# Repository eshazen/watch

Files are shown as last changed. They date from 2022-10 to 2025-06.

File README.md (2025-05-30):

# Smart Watch

See also:  [SOFTWARE.md](SOFTWARE.md)
<br> [BUILD.md](BUILD.md)

Imagining a device similar to a smart watch, but not intended to
connect to a phone and generate alerts.  Instead, I'd like:

* Large, easy-to-read e-ink time display
* Auxiliary info (possibly selected using button):
   * Multiple timezones
   * Alarm/timer time
   * Weather info
   * Any other not-quite realtime info pushed via WiFi

The watch would link to base stations at home and at work for updates.
This could be WiFi (power hungry!), or something like RFM69 (915 MHz).

The idea would be that the watch has WiFi but only powers up every 10min or
so and tries to connect to the last AP, otherwise tries a short list of AP.
Some fairly smart algorithm should recognize when not near an AP and give up,
checking at longer intervals.  A button press should be available to force
WiFi update.

## Rev 1.0

Ordered PCBs and BOM parts (Mouser) on 12/2/22.  

* [schematic](watch-pcb/watch-sch.pdf)

Radio is RFM69HCW (915MHz).  Display is waveshire e-link 1.54 in
(200x200 resolution).  RTC is PCF85263A.
There's an 8-pin (2x4) 2mm "service" connector with pinout:

| Pin | Function |
|-----|---|
| 1 | 3.3V |
| 2 | MOSI |
| 3 | MISO |
| 4 | SCK |
| 5 | nRESET |
| 6 | UART TX  |
| 7 | UART RX  |
| 8 | GND |

ATMega328 pin assignments:

| Pin | Function | Notes |
|-----|---|---|
| PB0 | eRST | e-ink reset |
| PB1 | eDC | e-ink data/control  |
| PB2 | RF_CS | Radio chip select |
| PB3 | MOSI | for radio and e-ink |
| PB4 | MISO | radio MISO |
| PB5 | SCK | for radio and e-ink |
| PB6 | LED1 | |
| PB7 | LED2 | |
|-----|----------|---------------------|
| PC0 | RF_RST | Radio reset |
| PC1 | SW1 | (not installed) |
| PC2 | SW2 | |
| PC3 | RTC_INT  | RTC interrupt |
| PC4 | RTC_SCL  | RTC I2C clock |
| PC5 | RTC_SDA  | RTC I2C data |
| PC6 | nRESET | MCU reset |
|-----|----------|---------------------|
| PD0 | RxD | UART input data |
| PD1 | TxD | UART output data |
| PD2 | SW3 | |
| PD3 | SW4 | |
| PD5 | DIO0 | Radio DIO0 |
| PD6 | eCS | e-ink chip select |
| PD7 | eBUSY | e-ink busy |

3D PCB view: 

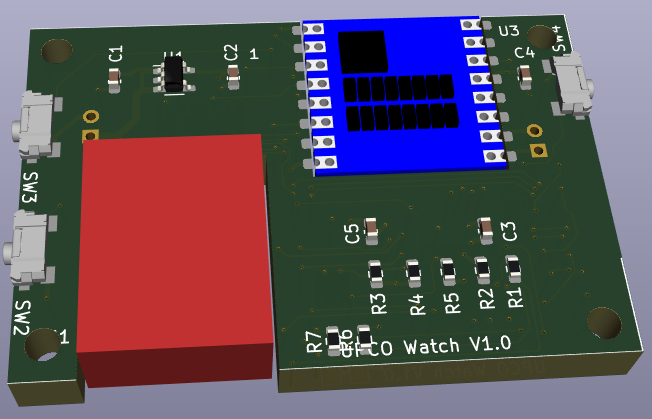
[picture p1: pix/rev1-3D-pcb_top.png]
front
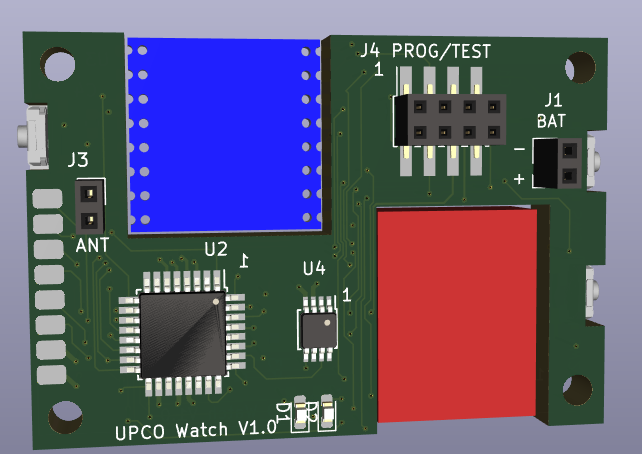
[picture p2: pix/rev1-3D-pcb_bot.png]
back
 

### Display

Ordered a black/red display from buydisplay.com.  This works ok but has
a ~15s refresh time and doesn't support fast/partial refresh.  My bad!

Ordered another from waveshare which is monochrome and does support
partial refresh.  Holding off on buying anything else until the display
part is working reasonably.

* Waveshare [page](https://www.waveshare.com/product/displays/e-paper/1.54inch-e-paper-module.htm?___SID=U)
[wiki](https://www.waveshare.com/wiki/1.54inch_e-Paper_Module) [data](https://www.waveshare.com/w/upload/e/e5/1.54inch_e-paper_V2_Datasheet.pdf)

This is reasonable, just a bit big.  Another alternative is the waveshare
1.02inch display.

### Radio

Meanwhile, Carlos (of MLRC) suggests BLE or VHF radio as an alternative
to WiFi.  This would require a bit of setup but would be much lower power.

#### VHF/UHF

RFM69 [data](https://cdn.sparkfun.com/datasheets/Wireless/General/RFM69HCW-V1.1.pdf) is 
interesting, but needs a 3 inch antenna.  Possibly it would work
OK if wrapped around the watch band?  These things are cheap ($6.50 for COM-13909 from
Sparkfun).  3.3V.  Needs 16mA to receive, 16..130mA to transmit (depends on settings).
Bit rates are modem-ish up to 156k.  Claims 50m range indoors.
Module is about 0.8" x 0.8" (20.3mm)

nRF24L01 and friends.  2.4GHz.  Bit rate s 250/1M/2M.  Power for Rx:
8.9-13.5mA Power for Tx: 8-11mA.  Fancier protocol with packet
retransmit, etc.  $21 each for WRL-00691.

#### ESP-01

ESP-01 Power Consumption:  
* 170mA working worst case
* 0.9mA "light sleep"
* 10uA "deep sleep"

Datasheet says "...sleep 300s and waking up to connect to the AP
(taking about 0.3~1s), the overall average current is less than 1mA.
Not clear how this is affected if multiple AP must be tried.  Need
to get some ESP-01 and play with them.

So we're looking at ~1mA minimum average power with capability to
deliver ~200mA.  For few days running it would be nice to have
~100mAh.

It seems that on ESP-01 modules you need to wire pin 8 to nRESET so it
can self-wake out of deep sleep.  Otherwise you can just call
ESP.deepSleep(0) and then use the MCU to pulse reset to wake it up.
(see
[note](https://www.tech-spy.co.uk/2019/04/enable-deep-sleep-esp-01/))

## Doco

* Display: [Mfgr page](https://www.buydisplay.com/red-1-54-inch-e-ink-display-module-200x200-for-arduino-raspberry-pi)
* [eInk.md](eInk.md)

## Parts?

* MCU:  ATMega1281-16AUR (64-TQFP)
   * Chosen for it's 8K RAM size so it can hold a 200x200 bitmap for the display
* RTC: 
   * Nisshinbo R2043T-E2-F (2129-R2043T-E2-FCT-ND).  10-VFSOP
   * Nisshinbo R2025S-E2-FE (2129-R2025S-E2-FECT-ND).  14-SOIC
* Thru pin socket
   * Mill-Max 0305-2-15-80-47-27-10-0  (0305-2-15-80-47-27-10-0)
* Side-mount switch
   * Panasonic EVQ-P4MB3K (P15507CT-ND)
* Battery Holder for CR1216
   * Linx BAT-HLD-012-SMT (BAT-HLD-012-SMT-ND)
* or Lipo battery.  There seem to be 100mAh batts 18x14.7mm which are
  cheap ($16/4 on Amazon with a little USB charger thing).  These are
  3.7V so we need a small-ish 3.3V LDO.
* WiFi
   * ESP-01 [data](https://www.microchip.ua/wireless/esp01.pdf)

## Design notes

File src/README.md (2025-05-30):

# Software for the watch

`watch` - simulation to run on xforms toolkit

`blinky` - initial LED/button test for AVR

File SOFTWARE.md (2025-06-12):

# Watch software

Initial software outline:

* Initialize RTC for 1 minute periodic interrupt
* Initialize AVR to go to sleep and wake on pin change interrupt from RTC
* On wakeup:  display time

Also need to provide some interface to set the time

## RTC

Basically working.  Time registers can be R/W and update as expected.

### Initialization

Set `TSPM[1:0] = 1` (nINTB output)

Set `INTA_enable` (addr 0x29) to `b'01000000'` (enable only periodic interrupt)

Set `Function` (addr 0x28) to `b'01000111'` (1 min periodic) -or-
<br> `b'00100111'` (1 sec periodic)

### Set / Read time

Time is in addresses 1-3 as BCD

### Interrupts

Setup AVR to interrupt on pin change on PC3.
Sleep to power-down mode and wake on interrupt.

Some example code:

```
set_sleep_mode(SLEEP_MODE_PWR_DOWN);
sleep_enable();
sleep_mode();
// wait for wake-up
sleep_disable();
power_all_enable();
```

## UART

UART working at 1200 baud (not 9600) with default 1MHz clock.

Need to find / recreate my_gets using the stdio hack.

## Display

Working after porting the code from Arduino.
The main limitation is the 1k maximum bitmap (64 x 128).

It would be nice to display an analog clock face.
This is complicated by the fact that the E-Ink display
is 200x200 and we don't have enough RAM (200x200/8=5000 bytes)
for a bitmap.

One solution is a partial bitmap (e.g. 64x128 = 1k), and
a bit of code which takes a display list and iterates
over it 8 times, clipping the lines into regions,
sending each to the display as it completes.

    /---- 200 ------\
    +----+----+----+----+ \
    | 64 | 64 | 64 | 64 | |
	|    |    |    |    | |
	|    |    |    |    | |
	|    |    |    |    | 200 
    +----+----+----+----+ |
	|    |    |    |    | |
	|    |    |    |    | |
	|    |    |    |    | /
	|    |    |    |    |
    +----+----+----+----+

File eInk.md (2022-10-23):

# EP-EPM0154-2R Software

## Installation

This display family is provided with some more-or-less working examples.  Installation steps:

Grab the zip from either the manufacturer page or local copy in `arduino` folder as 
`ER-EPM0154-2_Arduino_Tutorial.zip`.
This contains 3 sets of `Examples...` and `Libraries...` directories.

Copy the appropriate (in our case, the '..-2R') `Libraries` folder to the Arduino libraries
location, normally `~/Arduino/libraries/ER-EPM0154-2R`.

Then, make the following edits:

In `epdif.cpp` change "`#include <spi.h>`" to "`#include <SPI.h>`"

In `epdif.h` change "`#include <arduino.h>`" to "`#include <Arduino.h>`"

Now the example runs, at least in Arduino 1.8.19 under Ubuntu 22.04.

## Class Library

Here are the prototypes for `ER-EPM0154-2R.cpp`:

    Epd();
    ~Epd();
    int  Init(void);
    void SendCommand(unsigned char command);
    void SendData(unsigned char data);
    void WaitUntilIdle(void);
    void Reset(void);
     void SetFrameMemoryBlack(
        const unsigned char* image_buffer,
        int x,
        int y,
        int image_width,
        int image_height
    ); 
      void SetFrameMemoryRed(
        const unsigned char* image_buffer,
        int x,
        int y,
        int image_width,
        int image_height
    );   
    void SetFrameMemory(const unsigned char* frame_buffer_black, const unsigned char* frame_buffer_red);
    void ClearFrameMemory(void);
    void DisplayFrame(void);
    void Sleep(void);

### Use

Create one instance of `Epd` and use for all interactions with the display.

For drawing, the `paint` class manages a pixel buffer in RAM (keep in
mind RAM limitations!).  Each instance has a pointer to RAM area,
width, height and rotate flag (one of ROTATE_0, ROTATE_90, ROTATE_180,
ROTATE_270).  This is a 1-bit deep buffer, so you need two of them
for black and red.

There are a bunch of methods to draw pixels, characters, strings,
lines, rectangles, and circles to the buffer.

So, typically:

    unsigned char image[1200];
    Paint paint(image, 0, 0);
    Epd epd;

    if (epd.Init() != 0) fail();
    epd.ClearFrameMemory();
	
To write a string:

    paint.Clear(UNCOLORED);
    paint.DrawStringAt(0, 4, "Hello world!", &Font16, COLORED);
    epd.SetFrameMemoryBlack(paint.GetImage(), 0, 10, paint.GetWidth(), paint.GetHeight());
    epd.DisplayFrame();

### Methods

#### `Epd::Epd()`

Sets member variables for pin names (reset, dc, cs, bus) and width,
height from constants. Pins are defined in `epdif.h` while `width` and
`height` are define in `ER-EPM0154-2R.h`.

#### `Epd::Init()`

Initialize SPI via `EpdIf::IfINit()` (in `epdif.cpp`).  Sets pin modes
and initialize SPI.

#### `void Epd::SetFrameMemoryRed(`
#### `void Epd::SetFrameMemoryBlack(`

    const unsigned char* image_buffer,
    int x,
    int y,
    int image_width,
    int image_height)`
	
Copy image buffer to frame memory at specified coordinates.  Don't update display	

#### `void Epd::SetFrameMemory(const unsigned char* frame_buffer_black, const unsigned char* frame_buffer_red)`

Set frame memory from images in flash.

#### `Paint::Paint(unsigned char* image, int width, int height)`

Create a paint instance with pointer to RAM.  Width and height may be
set later (could be 0,0)

#### `Paint::Clear(int colored)`

Clear the image (slowly, with loop, calling `DrawAbsolutePixel`)

#### `void Paint::DrawAbsolutePixel(int x, int y, int colored)`

Set a pixel in the buffer (ignores rotation)

#### `void Paint::DrawPixel(int x, int y, int colored)`

Set a pixel in the buffer, taking into account rotation

#### `void Paint::DrawCharAt(int x, int y, char ascii_char, sFONT* font, int colored)`

Draw a character.  Font choices supplied (constants, stored in flash,
128 chars per font):

    Font8  (5 x 8)    1 byte/char  752 bytes
	Font12 (7 x 12)   1 byte/char  1128 bytes
	Font16 (11 x 16)  2 byte/char  3008 bytes
	Font20 (14 x 20)  2 byte/char  3760 bytes
	Font24 (17 x 24)  3 byte/char  6768 bytes
	
#### `Paint::DrawStringAt(int x, int y, const char* text, sFONT* font, int colored)`

Draw a string from RAM.  Note that there is (currently) no function to
write strings stored in flash.

There are various drawing functions:

#### `void Paint::DrawLine(int x0, int y0, int x1, int y1, int colored)`
#### `void Paint::DrawHorizontalLine(int x, int y, int line_width, int colored)`
#### `void Paint::DrawVerticalLine(int x, int y, int line_height, int colored)`
#### `void Paint::DrawRectangle(int x0, int y0, int x1, int y1, int colored)`
#### `void Paint::DrawFilledRectangle(int x0, int y0, int x1, int y1, int colored)`
#### `void Paint::DrawCircle(int x, int y, int radius, int colored)`
#### `void Paint::DrawFilledCircle(int x, int y, int radius, int colored)`

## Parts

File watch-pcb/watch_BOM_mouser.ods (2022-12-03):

Item | Qty | Reference(s) | Value | LibPart | Footprint | CatNo
1 | 2 | C1, C2 | 1uF | Device:C_Small | Capacitor_SMD:C_0603_1608Metric | 187-CL10B105KP8NNNC | Mouser
2 | 3 | C3, C4, C5 | 0.1uF | Device:C_Small | Capacitor_SMD:C_0603_1608Metric | 603-CC603KRX7R7BB104 | Mouser
3 | 2 | D1, D2 | LED | Device:LED | LED_SMD:LED_0603_1608Metric_Pad1.05x0.95mm_HandSolder | 755-SML-D12U8WT86 | Mouser
5 | 1 | J1 | Conn_01x02 | Connector_Generic:Conn_01x02 | Connector_PinSocket_2.00mm:PinSocket_1x02_P2.00mm_Vertical | 571-1-2355045-0 | Mouser
6 | 1 | J2 | Conn_01x08 | Connector_Generic:Conn_01x08 | E-Ink:Waveshare_1.54
7 | 1 | J3 | Conn_01x02_Female | Connector:Conn_01x02_Female | Connector_PinSocket_2.00mm:PinSocket_1x02_P2.00mm_Vertical | 571-1-2355045-0 | Mouser
8 | 1 | J4 | Conn_01x08 | Connector_Generic:Conn_01x08 | Connector_PinSocket_2.00mm:PinSocket_2x04_P2.00mm_Vertical_SMD | 538-87759-0874 | Mouser
9 | 1 | N1 | Battery | Mechanical:Housing | Battery:LiPo-100mAh
10 | 3 | R1, R2, R3 | 10k | Device:R_US | Resistor_SMD:R_0603_1608Metric | 71-CRCW060310K0FKEAC | Mouser
11 | 2 | R4, R5 | 4.7k | Device:R_US | Resistor_SMD:R_0603_1608Metric | 71-CRCW06034K70FKEAH | Mouser
12 | 2 | R6, R7 | 330 | Device:R_US | Resistor_SMD:R_0603_1608Metric | 71-CRCW0603330RFKEAH | Mouser
13 | 4 | SW1, SW2, SW3, SW4 | EVQ-P4MB3K | Switch:SW_Push | TinySwitch:EVQ-P4 | P15507CT-ND | Mouser
14 | 1 | U1 | NCP161 | Regulator_Linear:LP2985-1.8 | Package_TO_SOT_SMD:SOT-23-5 | 863-NCP161ASN330T1G | Mouser
15 | 1 | U2 | ATmega328-A | MCU_Microchip_ATmega:ATmega328-A | Package_QFP:TQFP-32_7x7mm_P0.8mm |  | eBay
16 | 1 | U3 | RFM69HCW | RF_Module:RFM69HCW | RFM69:RFM69HCW | 474-COM-13909 | Mouser
17 | 1 | U4 | PCF85263ATT | Timer_RTC:PCF85263ATT | Package_SO:TSSOP-8_3x3mm_P0.65mm | 771-PCF85263ATT/AJ | Mouser

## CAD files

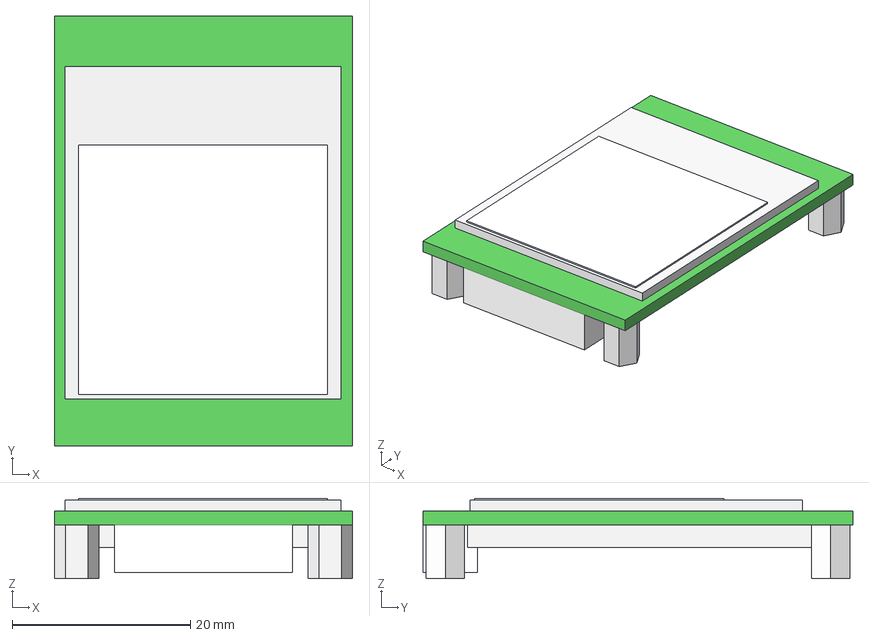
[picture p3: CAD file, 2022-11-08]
3D/watch-Matrix_Union002.step
33.5 x 48.3 x 9.00 mm

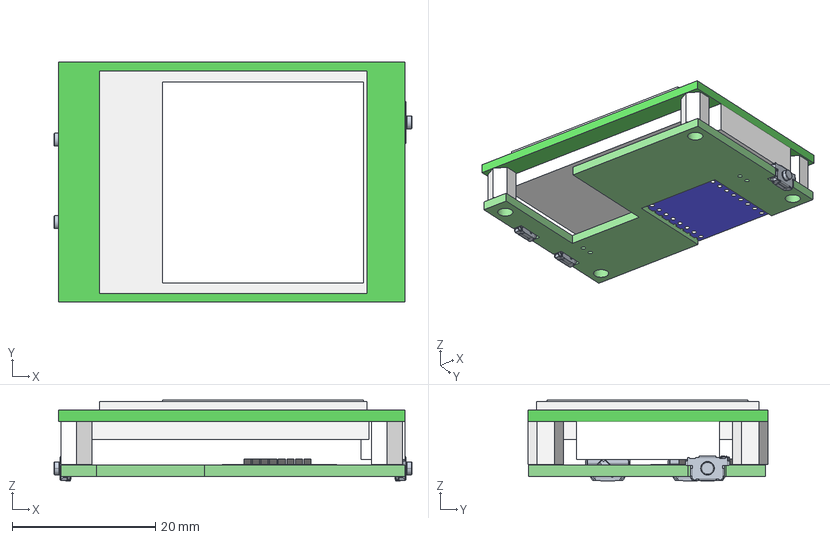
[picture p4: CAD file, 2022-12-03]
watch-pcb/watch.step
49.9 x 33.5 x 11.2 mm
watch PCB

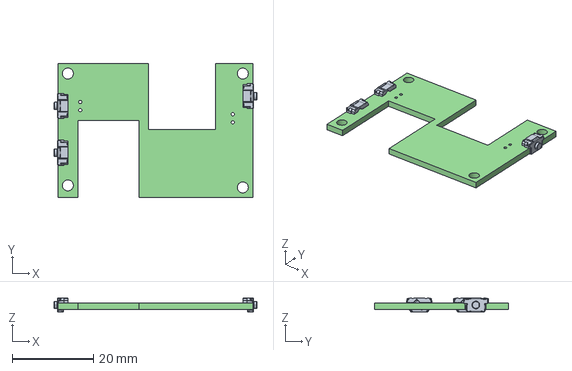
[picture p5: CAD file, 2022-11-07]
3D/watch.step
49.9 x 33.0 x 3.50 mm
watch PCB

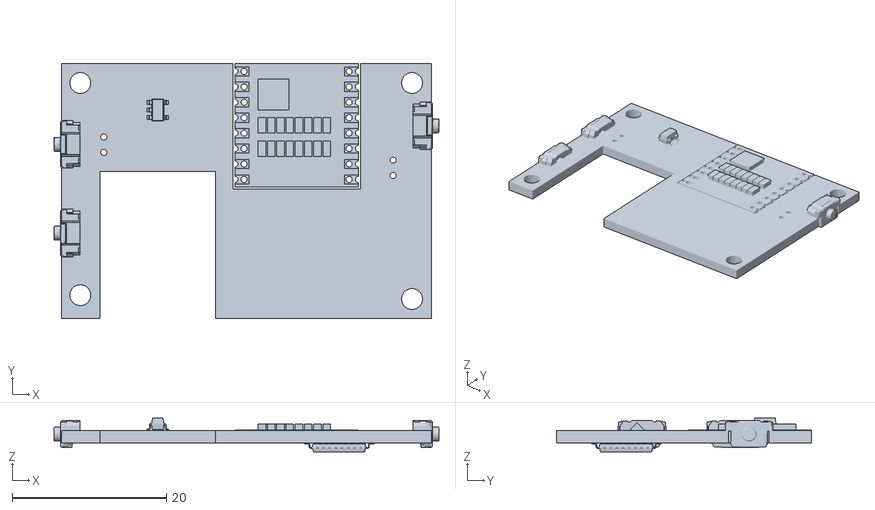
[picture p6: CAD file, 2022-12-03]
watch-pcb/Unnamed-watch-pcb 1.stl
49.9 x 33.0 x 4.35

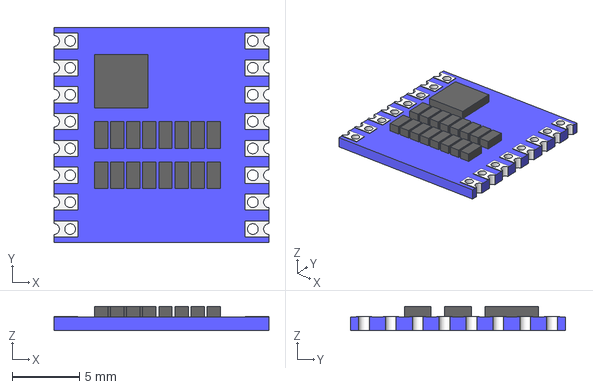
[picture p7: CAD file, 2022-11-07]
3D/rfm69hcw-difference.step
16.0 x 16.0 x 1.80 mm

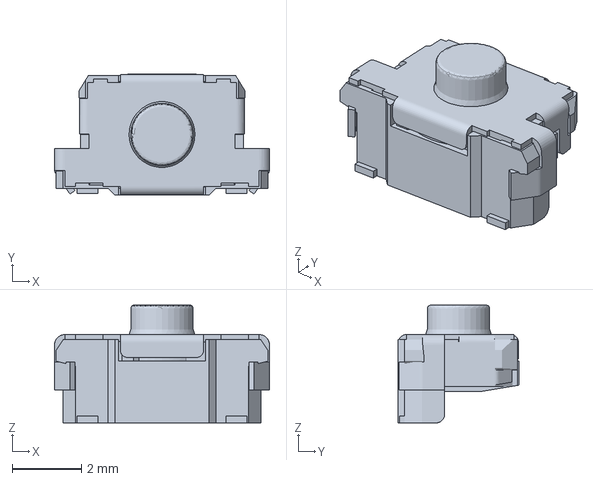
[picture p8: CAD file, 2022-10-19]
3D/Unnamed-EVQP4KB3Q.3mf
6.20 x 3.50 x 3.40 mm

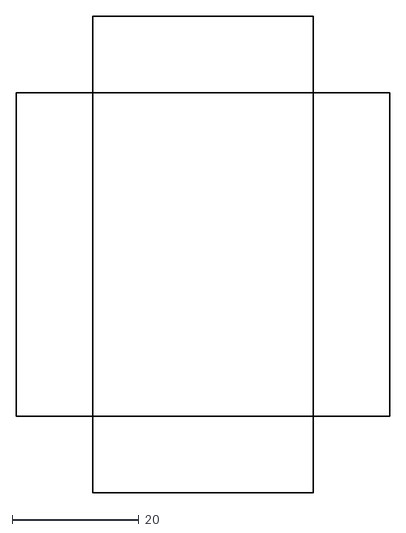
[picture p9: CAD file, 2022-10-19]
3D/simple_case.dxf
58.8 x 75.0

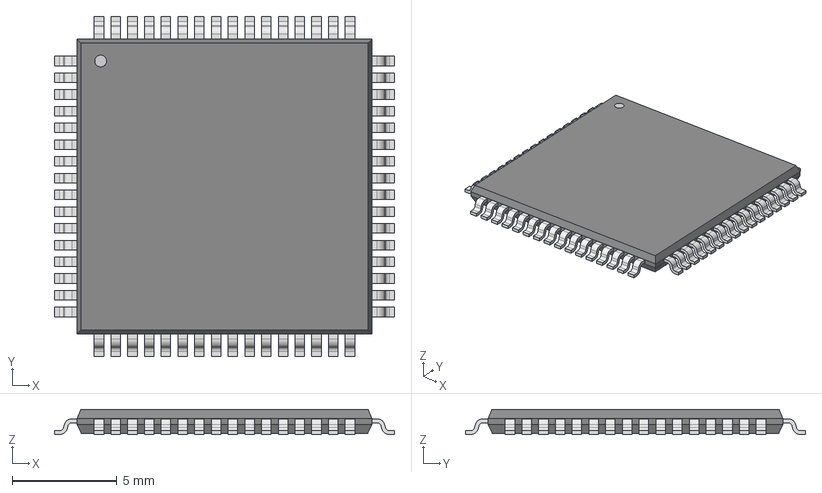
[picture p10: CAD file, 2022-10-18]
3D/64A_ATM.step
16.3 x 16.3 x 1.20 mm

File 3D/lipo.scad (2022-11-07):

color("brown")
cube( [14, 18, 7]);

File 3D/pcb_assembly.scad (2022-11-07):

// import( "Unnamed-watch.amf", convexity=3);
import( "Unnamed-watch.stl", convexity=3);

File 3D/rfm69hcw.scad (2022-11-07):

// RFM69HCW simple model

pcb_wid = 16;
pcb_len = 16;
pcb_thk = 1.0;
comp_hgt = 0.8;
pitch = 2.0;

hole_dia = 0.8;
pad_wid = 1.8;
pad_len = 1.2;

e = 0.1;

$fn = 32;


module part_at( x, y, wid, leng, thk) {
     translate( [x, y, pcb_thk])
	  color("black")
	  cube( [wid, leng, thk]);
}


module pcb() {
	  color("blue")
	       cube( [pcb_wid, pcb_len, pcb_thk]);

	  // pads
	  translate( [0, 1-pad_len/2, pcb_thk]) {
	       for( y=[0:2:14]) {
		    translate( [0, y, 0])
			 cube( [pad_wid, pad_len, e/2]);
		    translate( [pcb_wid-pad_wid, y, 0])
			 cube( [pad_wid, pad_len, e/2]);
	       }
	  }

	  // parts
	  part_at( 3, 10, 4, 4, 0.8);
	  for( x=[3:1.2:12]) {
	       part_at( x, 7, 1, 2, .8);
	       part_at( x, 4, 1, 2, .8);
	  }
}

translate( [-pcb_wid/2, -pcb_len/2, 0]) {

     difference() {
	  pcb();

	  // castllations
	  translate( [0, 1, -e]) {
	       for( y=[0:2:14]) {
		    translate( [0, y, 0]) {
			 cylinder( h=pcb_thk+2*e, d=hole_dia);
			 translate( [1.2, 0, 0])
			      cylinder( h=pcb_thk+2*e, d=hole_dia);
		    }
		    translate( [pcb_wid, y, 0]) {
			 cylinder( h=pcb_thk+2*e, d=hole_dia);
			 translate( [-1.2, 0, 0])
				    cylinder( h=pcb_thk+2*e, d=hole_dia);
		    }
	       }
	  }
     }

}

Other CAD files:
3D/Unnamed-watch.stl
watch-pcb/Unnamed-watch 1.stl
3D/EVQP4-HB3B_KB3Q_MB3K.STEP
3D/qfp64.stl
3D/watch.scad
3D/Unnamed-watch.amf

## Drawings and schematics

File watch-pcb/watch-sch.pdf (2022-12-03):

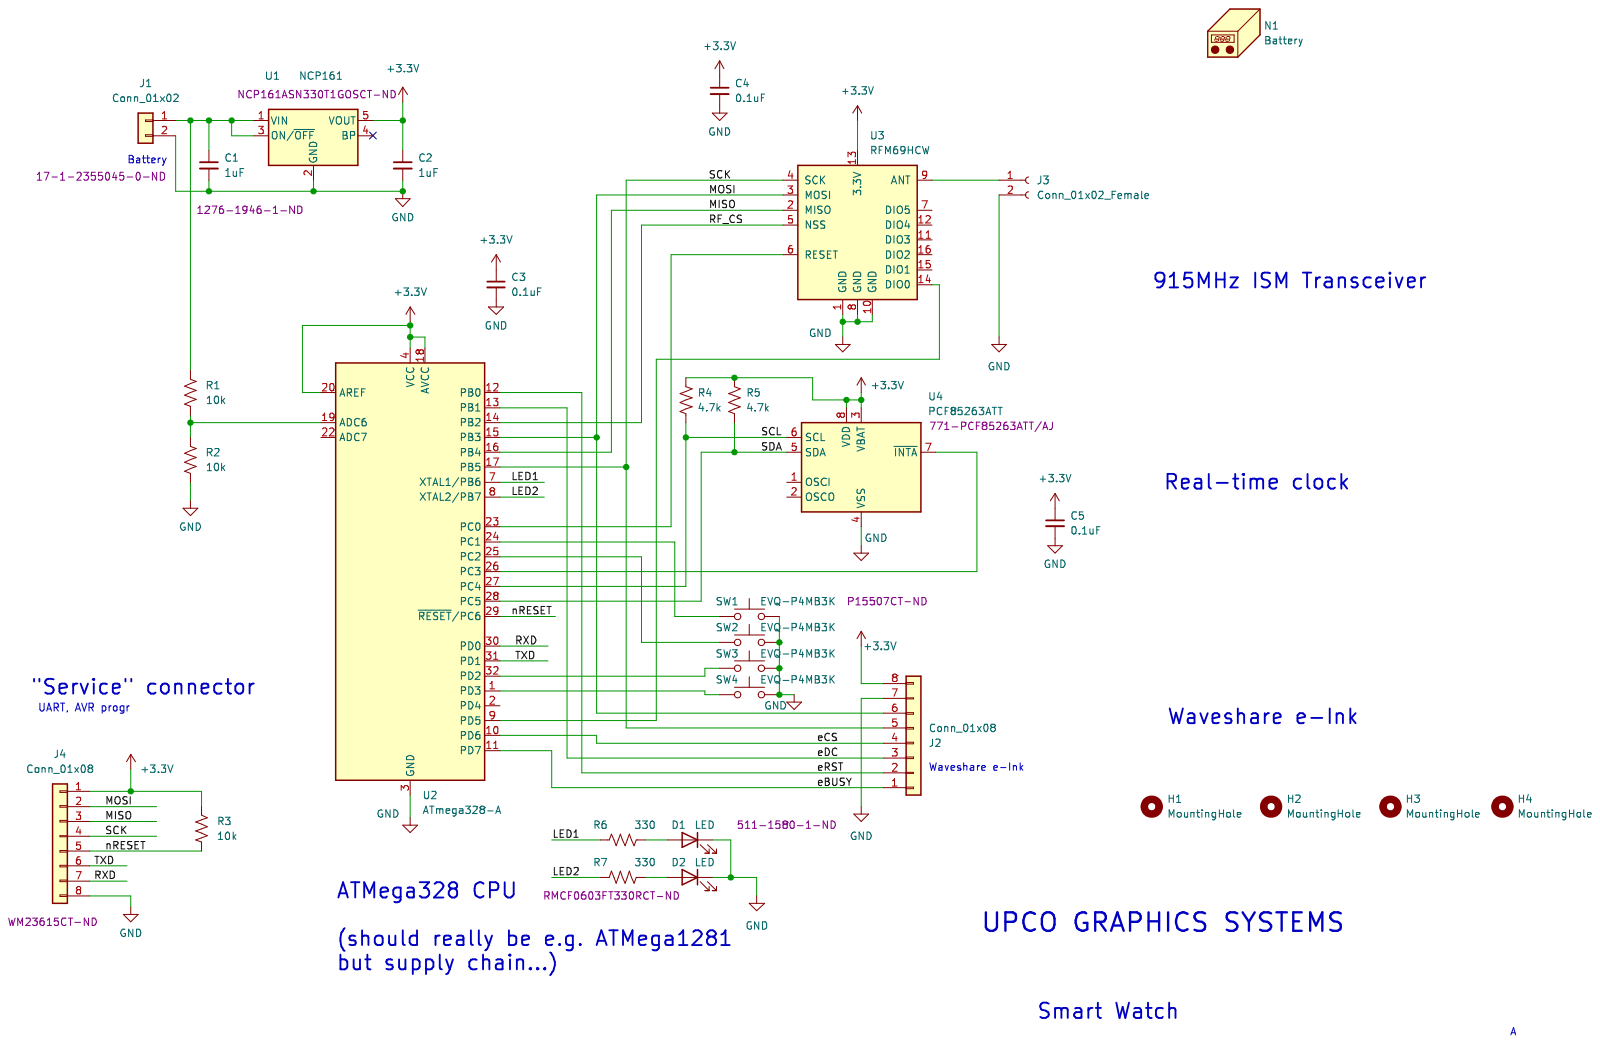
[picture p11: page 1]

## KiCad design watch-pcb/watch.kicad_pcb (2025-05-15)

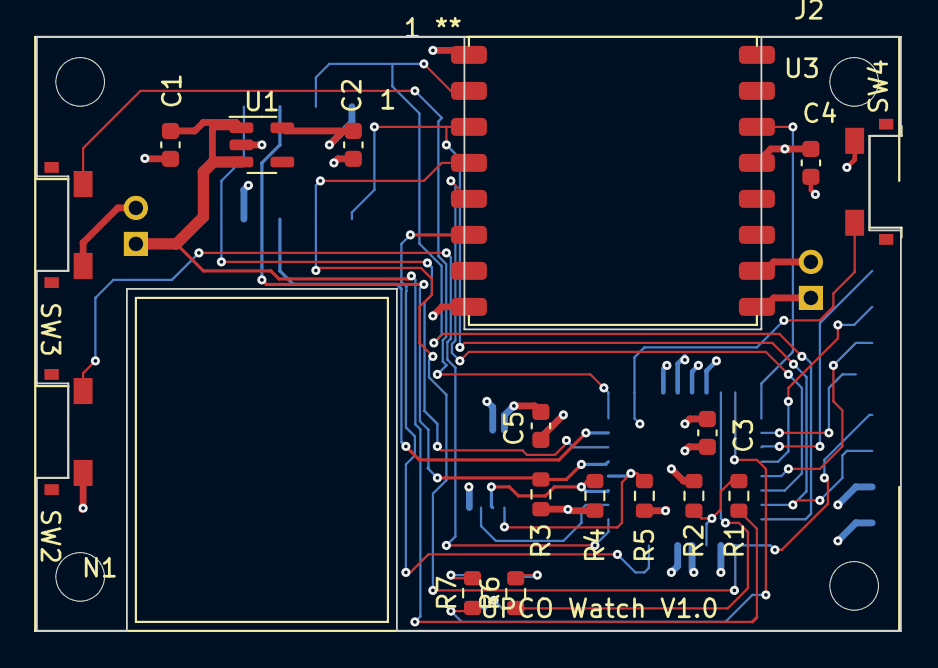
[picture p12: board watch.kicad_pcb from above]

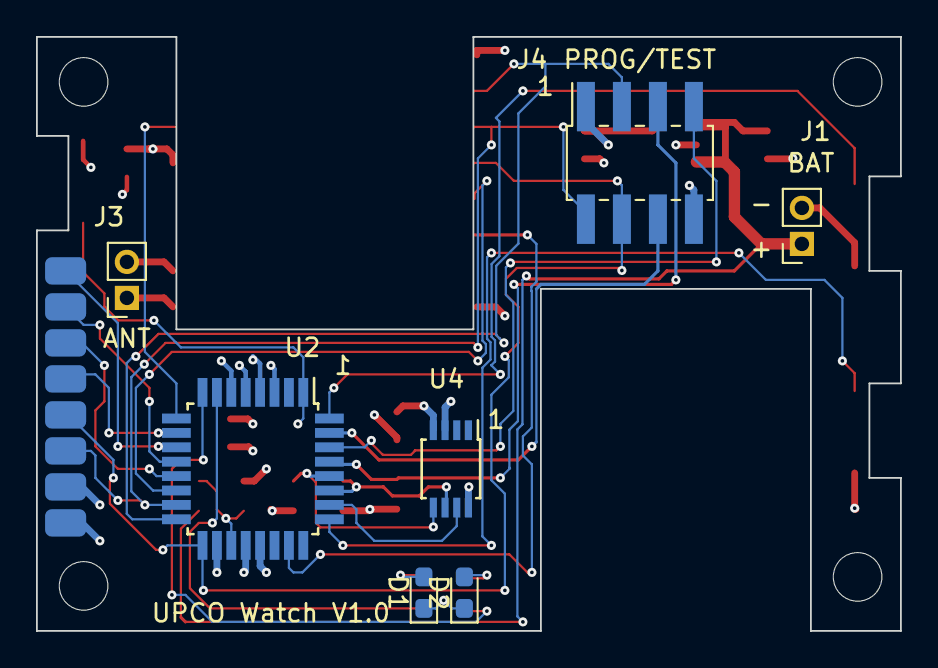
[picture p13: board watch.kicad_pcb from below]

Board: 4 copper layers, 48.0 x 33.0 mm, 26 parts (7 on the bottom side), 28 nets.

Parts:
C1, C2: 1uF; C_0603_1608Metric
C3, C4, C5: 0.1uF; C_0603_1608Metric
D1, D2: LED; LED_0603_1608Metric_Pad1.05x0.95mm_HandSolder
J1: Conn_01x02; PinSocket_1x02_P2.00mm_Vertical
J2: Conn_01x08; Waveshare_1.54_no3D
J3: Conn_01x02_Female; PinSocket_1x02_P2.00mm_Vertical
J4: Conn_01x08; PinSocket_2x04_P2.00mm_Vertical_SMD
N1: Battery; LiPo-100mAh
R1, R2, R3: 10k; R_0603_1608Metric
R4, R5: 4.7k; R_0603_1608Metric
R6, R7: 330; R_0603_1608Metric
SW2, SW3, SW4: EVQ-P4MB3K; EVQ-P4
U1: NCP161; SOT-23-5
U2: ATmega328-A; TQFP-32_7x7mm_P0.8mm
U3: RFM69HCW
U4: PCF85263ATT; TSSOP-8_3x3mm_P0.65mm

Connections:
+3.3V: C2.1, C3.1, C4.1, C5.1, J2.8, J4.1, R3.1, R4.1, R5.1, U1.5 (VOUT), U2.4 (VCC), U2.6 (VCC), U2.18 (AVCC), U2.20 (AREF), U3.13 (3.3V), U4.3 (VBAT), U4.8 (VDD)
/LED1: R6.1, U2.7 (XTAL1/PB6)
/LED2: R7.1, U2.8 (XTAL2/PB7)
/MISO: J4.3, U2.16 (PB4), U3.2 (MISO)
/MOSI: J2.6, J4.2, U2.15 (PB3), U3.3 (MOSI)
/RF_CS: U2.14 (PB2), U3.5 (NSS)
/RXD: J4.7, U2.30 (PD0)
/SCK: J2.5, J4.4, U2.17 (PB5), U3.4 (SCK)
/SCL: R4.2, U2.27 (PC4), U4.6 (SCL)
/SDA: R5.2, U2.28 (PC5), U4.5 (SDA)
/TXD: J4.6, U2.31 (PD1)
/eBUSY: J2.1, U2.11 (PD7)
/eCS: J2.4, U2.10 (PD6)
/eDC: J2.3, U2.13 (PB1)
/eRST: J2.2, U2.12 (PB0)
/nRESET: J4.5, R3.2, U2.29 (~RESET/PC6)
GND: C1.2, C2.2, C3.2, C4.2, C5.2, D1.1 (K), D2.1 (K), J1.2, J2.7, J3.2, J4.8, R2.2, SW2.2, SW3.2, SW4.2, U1.2 (GND), U2.3 (GND), U2.5 (GND), U2.21 (GND), U3.1 (GND), U3.8 (GND), U3.10 (GND), U4.4 (VSS)
unnamed: C1.1, J1.1, R1.1, U1.1 (VIN), U1.3 (ON/~OFF)
unnamed: D1.2 (A), R6.2
unnamed: D2.2 (A), R7.2
unnamed: J3.1, U3.9 (ANT)
unnamed: R1.2, R2.1, U2.19 (ADC6)
unnamed: SW2.1, U2.25 (PC2)
unnamed: SW3.1, U2.32 (PD2)
unnamed: SW4.1, U2.1 (PD3)
unnamed: U2.9 (PD5), U3.14 (DIO0)
unnamed: U2.23 (PC0), U3.6 (RESET)
unnamed: U2.26 (PC3), U4.7 (~INTA)

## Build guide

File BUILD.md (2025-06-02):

# V1.0 build log

Some issues from looking things over before assembly:

* I(Q) of the regulator may be an issue.  Spec'd at 70uA.
For a 100mAh battery math says ~1500 hours so maybe fine.
* Not sure the RFM69 radio is really useful.  Ideally WiFi
so can connect at home and on campus periodically.

An alternative would be to use an ESP8266 ESP-12F module
(24x16mm).  (the RFM69 site is 16x16mm).

Or another alternative would be to carry in my backpack
or pocket a "bridge" device with WiFi and an RFM69.
It could even have GPS so it knows it's location.

First step is to assemble a board and get the display,
RTC, buttons etc working.

missing RTC crystal!
maybe 300-8301-ND

# 2025-05-31

* ISP, blinky and switches working!
* UART working after wire patch to Rx (open PCB trace??)
* RTC is missing crystal.  Ordered some from Amazon
* Found an I2C library from the BlinkyColorPOV project and copied to `i2c.c`.

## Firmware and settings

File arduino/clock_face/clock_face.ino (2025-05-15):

//
// try to draw a clock face
//


#include <SPI.h>
#include "epd1in54_V2.h"
#include "epdpaint.h"
#include <stdio.h>

Epd epd;
unsigned char image[1024];	// big enough for 128x64
Paint paint(image, 0, 0);

#define COLORED     0
#define UNCOLORED   1

int hours = 1;
int minutes = 15;

void show_clock(int hours, int minutes);

void setup()
{
  // put your setup code here, to run once:
  epd.LDirInit();
  epd.Clear();

  paint.SetWidth(64);
  paint.SetHeight(128);

  paint.Clear(UNCOLORED);

}

void loop()
{
  show_clock( hours, minutes);
  epd.SetFrameMemory(paint.GetImage(), 10, 10, paint.GetWidth(), paint.GetHeight());
  epd.DisplayFrame();
  ++minutes;
  if( minutes == 60)
    ++hours;
  delay(1);
}

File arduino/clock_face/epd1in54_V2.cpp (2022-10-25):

/*****************************************************************************
 * | File      	:   epd1in54_V2.cpp
 * | Author      :   Waveshare team
 * | Function    :   1.54inch e-paper V2
 * | Info        :
 *----------------
 * |	This version:   V1.0
 * | Date        :   2019-06-24
 * | Info        :
#
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
******************************************************************************/
#include <stdlib.h>
#include "epd1in54_V2.h"


// waveform full refresh
unsigned char WF_Full_1IN54[159] =
  {											
    0x80,	0x48,	0x40,	0x0,	0x0,	0x0,	0x0,	0x0,	0x0,	0x0,	0x0,	0x0,
    0x40,	0x48,	0x80,	0x0,	0x0,	0x0,	0x0,	0x0,	0x0,	0x0,	0x0,	0x0,
    0x80,	0x48,	0x40,	0x0,	0x0,	0x0,	0x0,	0x0,	0x0,	0x0,	0x0,	0x0,
    0x40,	0x48,	0x80,	0x0,	0x0,	0x0,	0x0,	0x0,	0x0,	0x0,	0x0,	0x0,
    0x0,	0x0,	0x0,	0x0,	0x0,	0x0,	0x0,	0x0,	0x0,	0x0,	0x0,	0x0,
    0xA,	0x0,	0x0,	0x0,	0x0,	0x0,	0x0,					
    0x8,	0x1,	0x0,	0x8,	0x1,	0x0,	0x2,					
    0xA,	0x0,	0x0,	0x0,	0x0,	0x0,	0x0,					
    0x0,	0x0,	0x0,	0x0,	0x0,	0x0,	0x0,					
    0x0,	0x0,	0x0,	0x0,	0x0,	0x0,	0x0,					
    0x0,	0x0,	0x0,	0x0,	0x0,	0x0,	0x0,					
    0x0,	0x0,	0x0,	0x0,	0x0,	0x0,	0x0,					
    0x0,	0x0,	0x0,	0x0,	0x0,	0x0,	0x0,					
    0x0,	0x0,	0x0,	0x0,	0x0,	0x0,	0x0,					
    0x0,	0x0,	0x0,	0x0,	0x0,	0x0,	0x0,					
    0x0,	0x0,	0x0,	0x0,	0x0,	0x0,	0x0,					
    0x0,	0x0,	0x0,	0x0,	0x0,	0x0,	0x0,					
    0x22,	0x22,	0x22,	0x22,	0x22,	0x22,	0x0,	0x0,	0x0,			
    0x22,	0x17,	0x41,	0x0,	0x32,	0x20
  };

// waveform partial refresh(fast)
unsigned char WF_PARTIAL_1IN54_0[159] =
  {
    0x0,0x40,0x0,0x0,0x0,0x0,0x0,0x0,0x0,0x0,0x0,0x0,
    0x80,0x80,0x0,0x0,0x0,0x0,0x0,0x0,0x0,0x0,0x0,0x0,
    0x40,0x40,0x0,0x0,0x0,0x0,0x0,0x0,0x0,0x0,0x0,0x0,
    0x0,0x80,0x0,0x0,0x0,0x0,0x0,0x0,0x0,0x0,0x0,0x0,
    0x0,0x0,0x0,0x0,0x0,0x0,0x0,0x0,0x0,0x0,0x0,0x0,
    0xF,0x0,0x0,0x0,0x0,0x0,0x0,
    0x1,0x1,0x0,0x0,0x0,0x0,0x0,
    0x0,0x0,0x0,0x0,0x0,0x0,0x0,
    0x0,0x0,0x0,0x0,0x0,0x0,0x0,
    0x0,0x0,0x0,0x0,0x0,0x0,0x0,
    0x0,0x0,0x0,0x0,0x0,0x0,0x0,
    0x0,0x0,0x0,0x0,0x0,0x0,0x0,
    0x0,0x0,0x0,0x0,0x0,0x0,0x0,
    0x0,0x0,0x0,0x0,0x0,0x0,0x0,
    0x0,0x0,0x0,0x0,0x0,0x0,0x0,
    0x0,0x0,0x0,0x0,0x0,0x0,0x0,
    0x0,0x0,0x0,0x0,0x0,0x0,0x0,
    0x22,0x22,0x22,0x22,0x22,0x22,0x0,0x0,0x0,
    0x02,0x17,0x41,0xB0,0x32,0x28,
  };

Epd::~Epd()
{
};

Epd::Epd()
{
  reset_pin = RST_PIN;
  dc_pin = DC_PIN;
  cs_pin = CS_PIN;
  busy_pin = BUSY_PIN;
  width = EPD_WIDTH;
  height = EPD_HEIGHT;
};

/**
 *  @brief: basic function for sending commands
 */
void Epd::SendCommand(unsigned char command)
{
  DigitalWrite(dc_pin, LOW);
  SpiTransfer(command);
}

/**
 *  @brief: basic function for sending data
 */
void Epd::SendData(unsigned char data)
{
  DigitalWrite(dc_pin, HIGH);
  SpiTransfer(data);
}

/**
 *  @brief: Wait until the busy_pin goes HIGH
 */
void Epd::WaitUntilIdle(void)
{
  while(DigitalRead(busy_pin) == 1) {      //LOW: idle, HIGH: busy
    DelayMs(100);
  }
  DelayMs(200);
}

void Epd::Lut(unsigned char* lut)
{
  SendCommand(0x32);
  for(unsigned char i=0; i<153; i++)
    SendData(lut[i]);
  WaitUntilIdle();
}

void Epd::SetLut(unsigned char* lut)
{
  Lut(lut);
	
  SendCommand(0x3f);
  SendData(lut[153]);
	
  SendCommand(0x03);
  SendData(lut[154]);
	
  SendCommand(0x04);
  SendData(lut[155]);
  SendData(lut[156]);
  SendData(lut[157]);
	
  SendCommand(0x2c);
  SendData(lut[158]);
}

// High Direction
int Epd::HDirInit(void)
{
  /* this calls the peripheral hardware interface, see epdif */
  if (IfInit() != 0) {
    return -1;
  }
  /* EPD hardware init start */
  Reset();

  WaitUntilIdle();
  SendCommand(0x12);  //SWRESET
  WaitUntilIdle();

  SendCommand(0x01); //Driver output control
  SendData(0xC7);
  SendData(0x00);
  SendData(0x01);

  SendCommand(0x11); //data entry mode
  SendData(0x01);

  SendCommand(0x44); //set Ram-X address start/end position
  SendData(0x00);
  SendData(0x18);    //0x0C-->(18+1)*8=200

  SendCommand(0x45); //set Ram-Y address start/end position
  SendData(0xC7);   //0xC7-->(199+1)=200
  SendData(0x00);
  SendData(0x00);
  SendData(0x00);

  SendCommand(0x3C); //BorderWavefrom
  SendData(0x01);

  SendCommand(0x18);
  SendData(0x80);

  SendCommand(0x22); // //Load Temperature and waveform setting.
  SendData(0XB1);
  SendCommand(0x20);

  SendCommand(0x4E);   // set RAM x address count to 0;
  SendData(0x00);
  SendCommand(0x4F);   // set RAM y address count to 0X199;
  SendData(0xC7);
  SendData(0x00);
  WaitUntilIdle();

  SetLut(WF_Full_1IN54);
  /* EPD hardware init end */

  return 0;
}

// Low Direction
int Epd::LDirInit(void)
{
  /* this calls the peripheral hardware interface, see epdif */
  if (IfInit() != 0) {
    return -1;
  }
  /* EPD hardware init start */
  Reset();

  WaitUntilIdle();
  SendCommand(0x12);  //SWRESET
  WaitUntilIdle();

  SendCommand(0x01); //Driver output control
  SendData(0xC7);
  SendData(0x00);
  SendData(0x00);

  SendCommand(0x11); //data entry mode
  SendData(0x03);

  SendCommand(0x44);
  /* x point must be the multiple of 8 or the last 3 bits will be ignored */
  SendData((0 >> 3) & 0xFF);
  SendData((199 >> 3) & 0xFF);
  SendCommand(0x45);
  SendData(0 & 0xFF);
  SendData((0 >> 8) & 0xFF);
  SendData(199 & 0xFF);
  SendData((199 >> 8) & 0xFF);

  SendCommand(0x3C); //BorderWavefrom
  SendData(0x01);

  SendCommand(0x18);
  SendData(0x80);

  SendCommand(0x22); // //Load Temperature and waveform setting.
  SendData(0XB1);
  SendCommand(0x20);

  SendCommand(0x4E);   // set RAM x address count to 0;
  SendData(0x00);
  SendCommand(0x4F);   // set RAM y address count to 0X199;
  SendData(0xC7);
  SendData(0x00);
  WaitUntilIdle();

  SetLut(WF_Full_1IN54);
  /* EPD hardware init end */

  return 0;
}


/**
 *  @brief: module reset.
 *          often used to awaken the module in deep sleep,
 *          see Epd::Sleep();
 */
void Epd::Reset(void)
{
  DigitalWrite(reset_pin, HIGH);
  DelayMs(20);
  DigitalWrite(reset_pin, LOW);                //module reset
  DelayMs(5);
  DigitalWrite(reset_pin, HIGH);
  DelayMs(20);
}

void Epd::Clear(void)
{
  int w, h;
  w = (EPD_WIDTH % 8 == 0)? (EPD_WIDTH / 8 ): (EPD_WIDTH / 8 + 1);
  h = EPD_HEIGHT;
 
  SendCommand(0x24);
  for (int j = 0; j < h; j++) {
    for (int i = 0; i < w; i++) {
      SendData(0xff);
    }
  }
  SendCommand(0x26);
  for (int j = 0; j < h; j++) {
    for (int i = 0; i < w; i++) {
      SendData(0xff);
    }
  }
  //DISPLAY REFRESH
  DisplayFrame();
}

void Epd::Display(const unsigned char* frame_buffer)
{
  int w = (EPD_WIDTH % 8 == 0)? (EPD_WIDTH / 8 ): (EPD_WIDTH / 8 + 1);
  int h = EPD_HEIGHT;

  if (frame_buffer != NULL) {
    SendCommand(0x24);
    for (int j = 0; j < h; j++) {
      for (int i = 0; i < w; i++) {
	SendData(pgm_read_byte(&frame_buffer[i + j * w]));
      }
    }
  }

  //DISPLAY REFRESH
  DisplayFrame();
}
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

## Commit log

2022-10-18 starting 3D model
    [64A_ATM.step, qfp64.stl, watch.scad]
2022-10-19 working on 3D model
    [EVQP4-HB3B_KB3Q_MB3K.STEP, Unnamed-EVQP4KB3Q.3mf, simple_case.dxf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]
2022-10-22 starting schematic
    [watch-proto.kicad_pcb, watch-proto.kicad_sch, watch.kicad_pcb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]
2022-10-25 3D work
    [watch.scad]
2022-11-01 working on 3D
    [watch.scad]
2022-11-03 working on PCB
    [watch.kicad_pcb, watch.kicad_sch]
2022-11-03 working on layout
    [watch.kicad_pcb, watch.kicad_sch]
2022-11-04 layout in progress
    [watch.kicad_pcb, watch.kicad_sch]
2022-11-06 working on model
    [watch.scad]
2022-11-08 Update 3D
    [watch-Matrix_Union002.step, watch.kicad_pcb, watch.scad]
2022-12-03 as built PCB rev 1.0
    [Unnamed-watch 1.stl, Unnamed-watch-pcb 1.stl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]
2025-05-15 working on analog clock sw
    [watch.kicad_pcb]
2025-06-03 working on uart debug
2025-06-03 candidate I2C debug code
2025-06-04 tweak software, schem notes
    [watch.kicad_sch]
